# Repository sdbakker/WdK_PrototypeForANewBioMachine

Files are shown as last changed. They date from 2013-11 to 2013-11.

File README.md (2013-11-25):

# Prototype for a new BioMachine

This repository contains the simplified and stripped version of [Prototype for a new Bio Machine](http://ivanhenriques.com/2012/09/25/prototype-for-a-new-biomachine/ "Prototype for a new Bio Machine") by [Ivan Henriques](http://ivanhenriques.com "Ivan Henriques").

## Description of Files

* JuremaController
  Containes the arduino source code
* PlantController
  Contains the hardware schematics and material list

### JuremaController
* __JuremaController.ino__
  The controller source code
* twi.c 
  I2C library source code
* twi.h
  I2C library header file
* arduino-libraries-CapacitiveSensor.zip
  Arduino libarary for capacitive sensing 

### PlantController
* PlantController.sch
  CadSoft Eagle simplified schematic file of the PlantController main board
* PlantController.brd
  CadSoft Eagle board file of the PlantController main board
* __PlantControllerSimplified.png__
  Imange of simplified schematic of the main controller board
* __PlantController_brd.png__
  Image of main controller board

* PC_CapSense.sch
  CadSoft Eagle simplified schematic file of the sensor add-on board
* PC_CapSense.brd
  CadSoft Eagle board file of the sensor add-on board
* __PlantControllerSensorBoardSimplified.png__
  Image of simplified schematic of sensor add-on board
* __PC_CapSense_brd.png__
  Image of sensor add-on board layout

* __PlantController_BOM.pdf__
  Bill of materials with order numbers and URLs

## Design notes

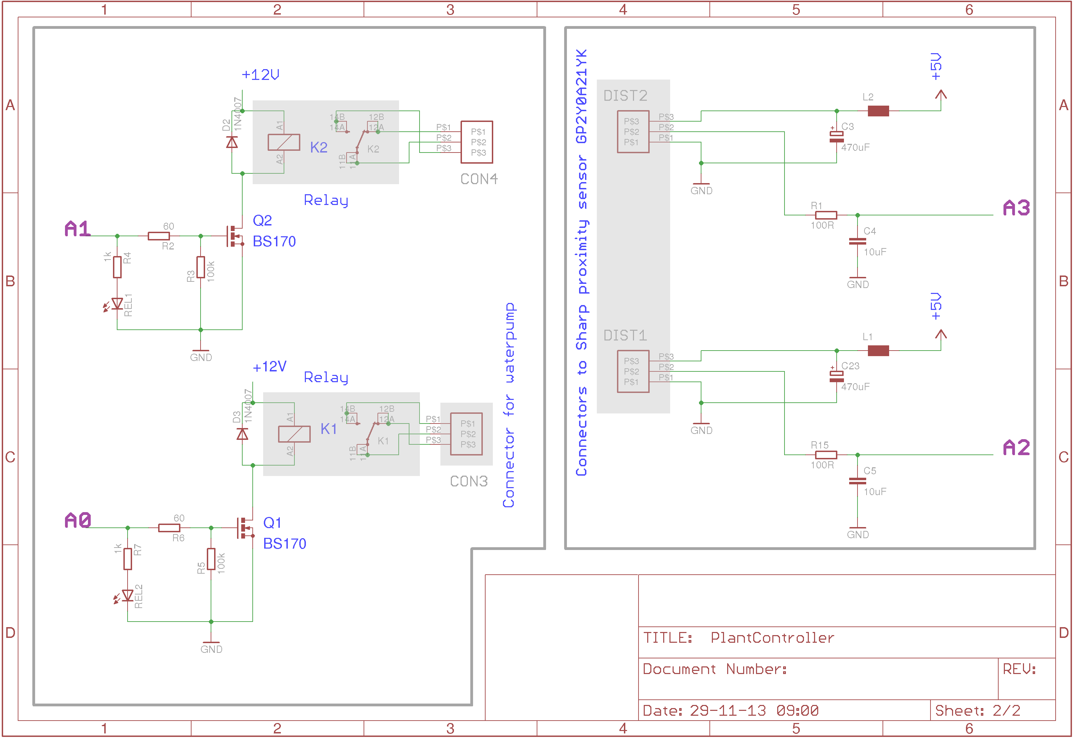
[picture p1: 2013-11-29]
PlantController/PlantControllerSimplified.png

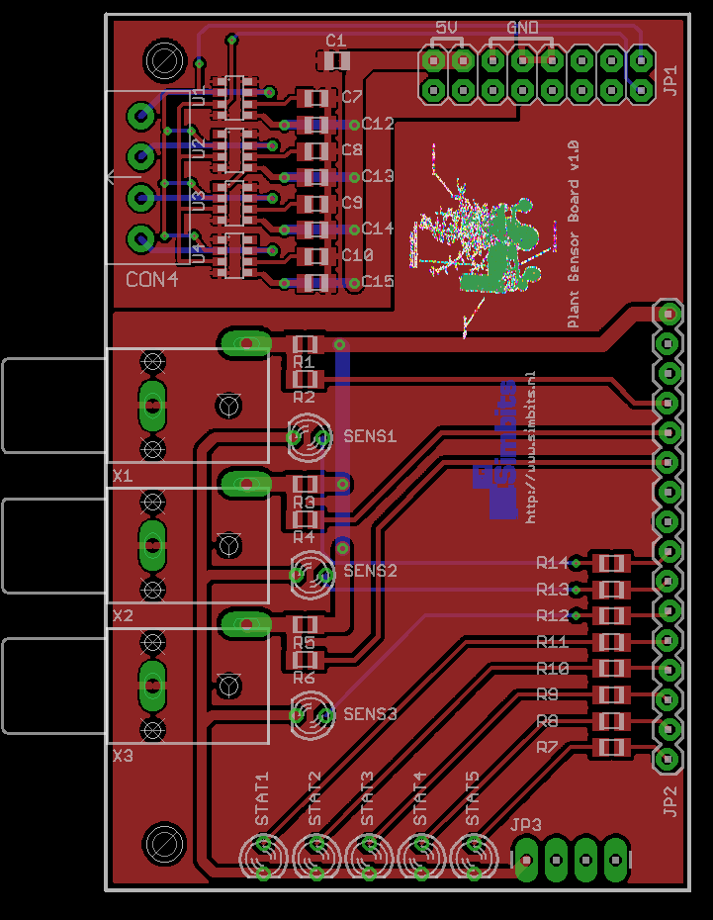
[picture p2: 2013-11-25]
PlantController/PC_CapSense_brd.png

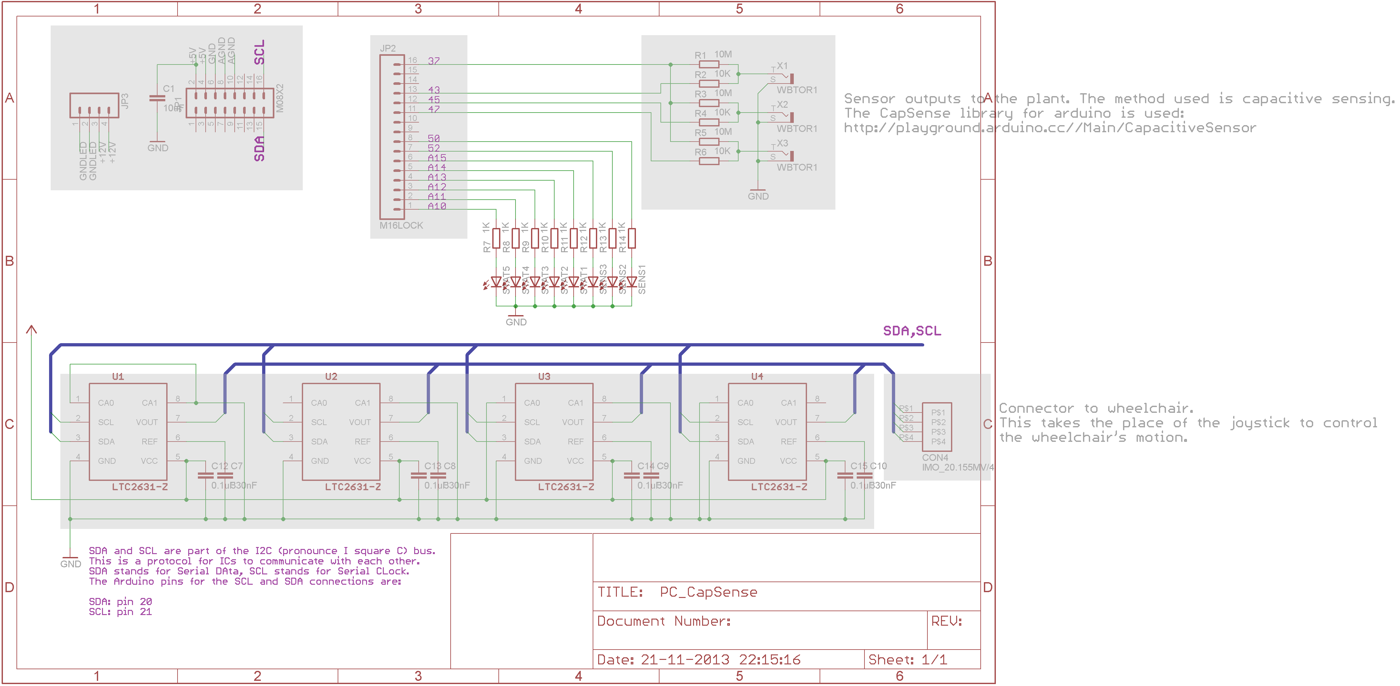
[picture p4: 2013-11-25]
PlantController/PlantControllerSensorBoardSimplified.png

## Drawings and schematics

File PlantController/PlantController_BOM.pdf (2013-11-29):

## PlantController_BOM

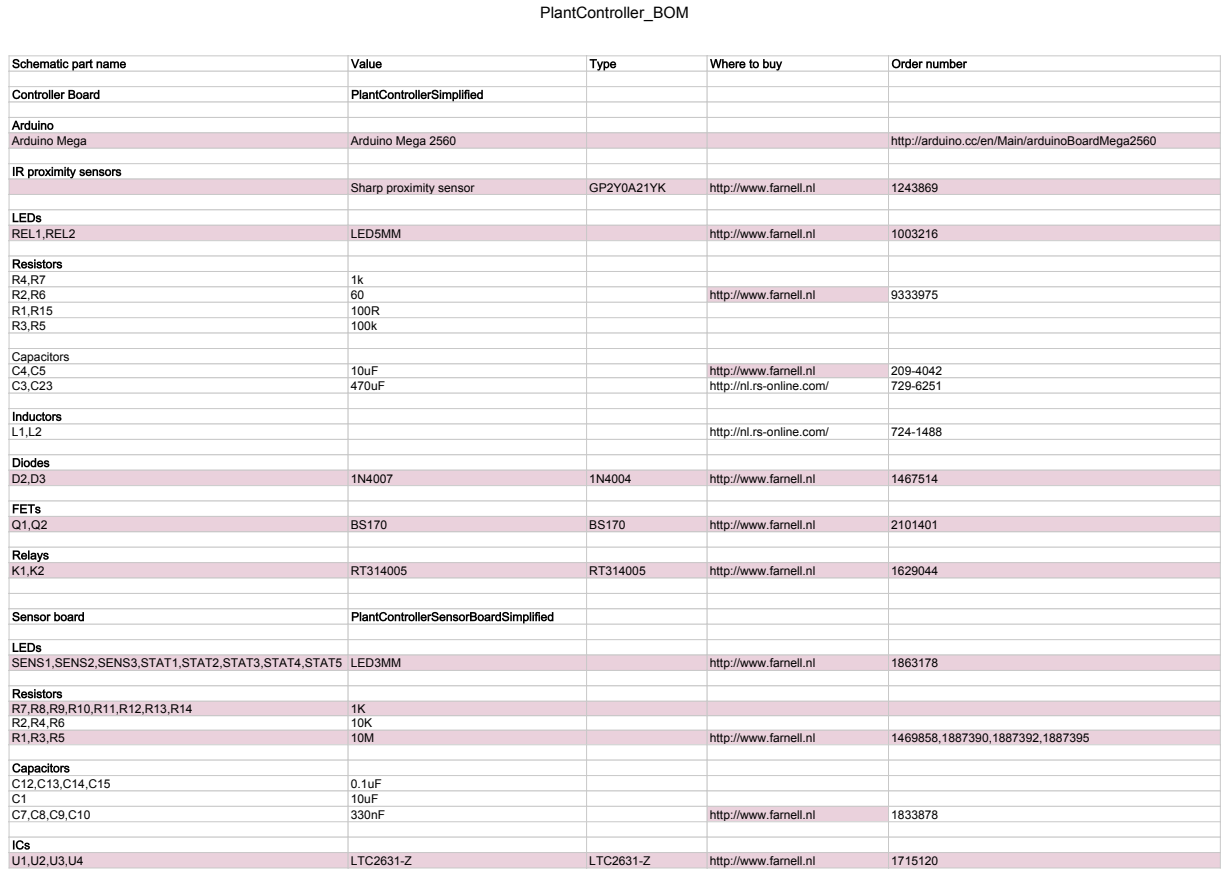
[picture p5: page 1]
Schematic part name; Value; Type; Where to buy; Order number; Controller Board; PlantControllerSimplified; Sensor board; PlantControllerSensorBoardSimplified

Arduino
Arduino Mega | Arduino Mega 2560 | http://arduino.cc/en/Main/arduinoBoardMega2560

IR proximity sensors

Sharp proximity sensor | GP2Y0A21YK | http://www.farnell.nl | 1243869

LEDs
REL1,REL2 | LED5MM | http://www.farnell.nl | 1003216

Resistors
R4,R7 | 1k
R2,R6 | 60 | http://www.farnell.nl | 9333975
R1,R15 | 100R
R3,R5 | 100k

Capacitors
C4,C5 | 10uF | http://www.farnell.nl | 209-4042
C3,C23 | 470uF | http://nl.rs-online.com/ | 729-6251

Inductors
L1,L2 | http://nl.rs-online.com/ | 724-1488

Diodes
D2,D3 | 1N4007 | 1N4004 | http://www.farnell.nl | 1467514

FETs
Q1,Q2 | BS170 | BS170 | http://www.farnell.nl | 2101401

Relays
K1,K2 | RT314005 | RT314005 | http://www.farnell.nl | 1629044

SENS1,SENS2,SENS3,STAT1,STAT2,STAT3,STAT4,STAT5 | LED3MM | http://www.farnell.nl | 1863178

R7,R8,R9,R10,R11,R12,R13,R14 | 1K
R2,R4,R6 | 10K
R1,R3,R5 | 10M | http://www.farnell.nl | 1469858,1887390,1887392,1887395

C12,C13,C14,C15 | 0.1uF
C1 | 10uF
C7,C8,C9,C10 | 330nF | http://www.farnell.nl | 1833878

ICs
U1,U2,U3,U4 | LTC2631-Z | LTC2631-Z | http://www.farnell.nl | 1715120

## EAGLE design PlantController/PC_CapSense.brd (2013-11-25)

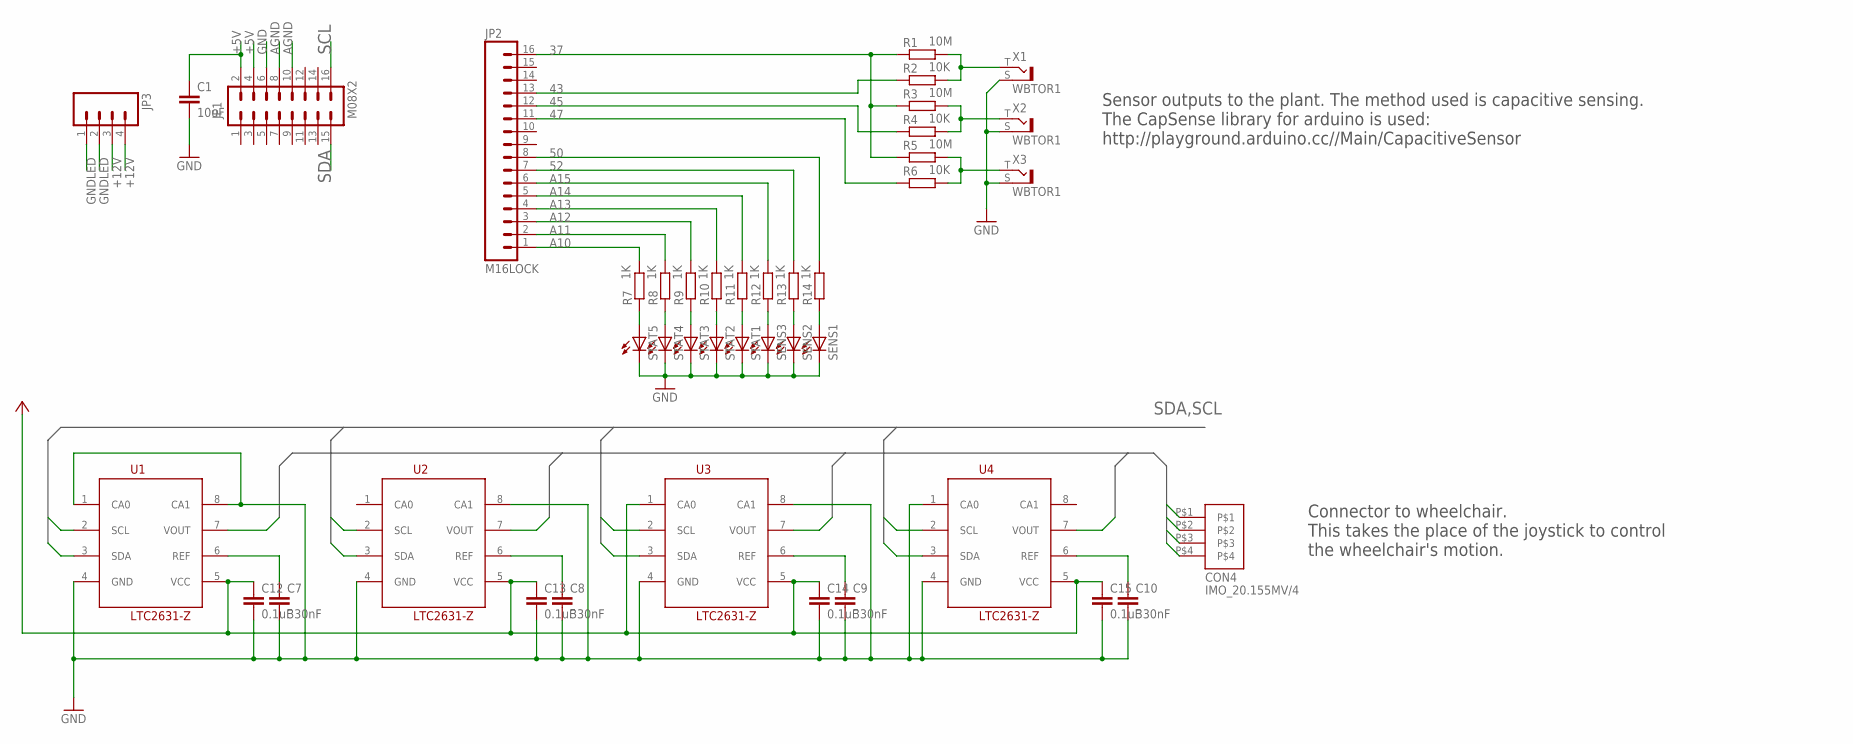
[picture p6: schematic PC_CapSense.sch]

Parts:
C1: 10uF; C0805
C7, C8, C9, C10: 330nF; C0805K
C12, C13, C14, C15: 0.1uF; C0805K
CON4: IMO_20.155MV/4
JP1: M08X2; 2X8
JP2: M16LOCK; 1X16_LOCK
JP3: M04LONGPADS; 1X04_LONGPADS
R1, R3, R5: 10M; M0805
R2, R4, R6: 10K; M0805
R7, R8, R9, R10, R11, R12, R13, R14: 1K; M0805
SENS1, SENS2, SENS3: LED3MM
STAT1, STAT2, STAT3, STAT4, STAT5: LED3MM
U1, U2, U3, U4: LTC2631-Z; TSOT23-8
X1, X2, X3: WBTOR1

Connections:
37: JP2.16, R1.1, R3.1, R5.1
43: JP2.13, R2.1
45: JP2.12, R4.1
47: JP2.11, R6.1
50: JP2.8, R14.2
52: JP2.7, R13.2
+5V: C1.1, C12.1, C13.1, C14.1, C15.1, JP1.2, JP1.4, U1.5 (VCC), U2.5 (VCC), U3.1 (CA0), U3.5 (VCC), U4.5 (VCC)
+12V: JP3.3, JP3.4
A10: JP2.1, R7.2
A11: JP2.2, R8.2
A12: JP2.3, R9.2
A13: JP2.4, R10.2
A14: JP2.5, R11.2
A15: JP2.6, R12.2
AGND: JP1.8, JP1.10, X1.S, X2.S, X3.S
GND: C1.2, C7.2, C8.2, C9.2, C10.2, C12.2, C13.2, C14.2, C15.2, JP1.6, U1.1 (CA0), U1.4 (GND), U1.8 (CA1), U2.4 (GND), U2.8 (CA1), U3.4 (GND), U3.8 (CA1), U4.1 (CA0), U4.4 (GND)
GNDLED: JP3.1, JP3.2, SENS1.K (C), SENS2.K (C), SENS3.K (C), STAT1.K (C), STAT2.K (C), STAT3.K (C), STAT4.K (C), STAT5.K (C)
unnamed: R1.2, R2.2, X1.T
unnamed: R3.2, R4.2, X2.T
unnamed: R5.2, R6.2, X3.T
unnamed: R7.1, STAT5.A
unnamed: R8.1, STAT4.A
unnamed: R9.1, STAT3.A
unnamed: R10.1, STAT2.A
unnamed: R11.1, STAT1.A
unnamed: R12.1, SENS3.A
unnamed: R13.1, SENS2.A
unnamed: R14.1, SENS1.A
unnamed: C10.1, U4.6 (REF)
unnamed: C9.1, U3.6 (REF)
unnamed: C8.1, U2.6 (REF)
unnamed: C7.1, U1.6 (REF)
SCL: JP1.16, U1.2 (SCL), U2.2 (SCL), U3.2 (SCL), U4.2 (SCL)
SDA: JP1.15, U1.3 (SDA), U2.3 (SDA), U3.3 (SDA), U4.3 (SDA)
VOUT0: CON4.P$1, U1.7 (VOUT)
VOUT1: CON4.P$2, U2.7 (VOUT)
VOUT2: CON4.P$3, U3.7 (VOUT)
VOUT3: CON4.P$4, U4.7 (VOUT)

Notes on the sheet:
Sensor outputs to the plant. The method used is capacitive sensing. The CapSense library for arduino is used: http://playground.arduino.cc//Main/CapacitiveSensor
Connector to wheelchair. This takes the place of the joystick to control the wheelchair's motion.

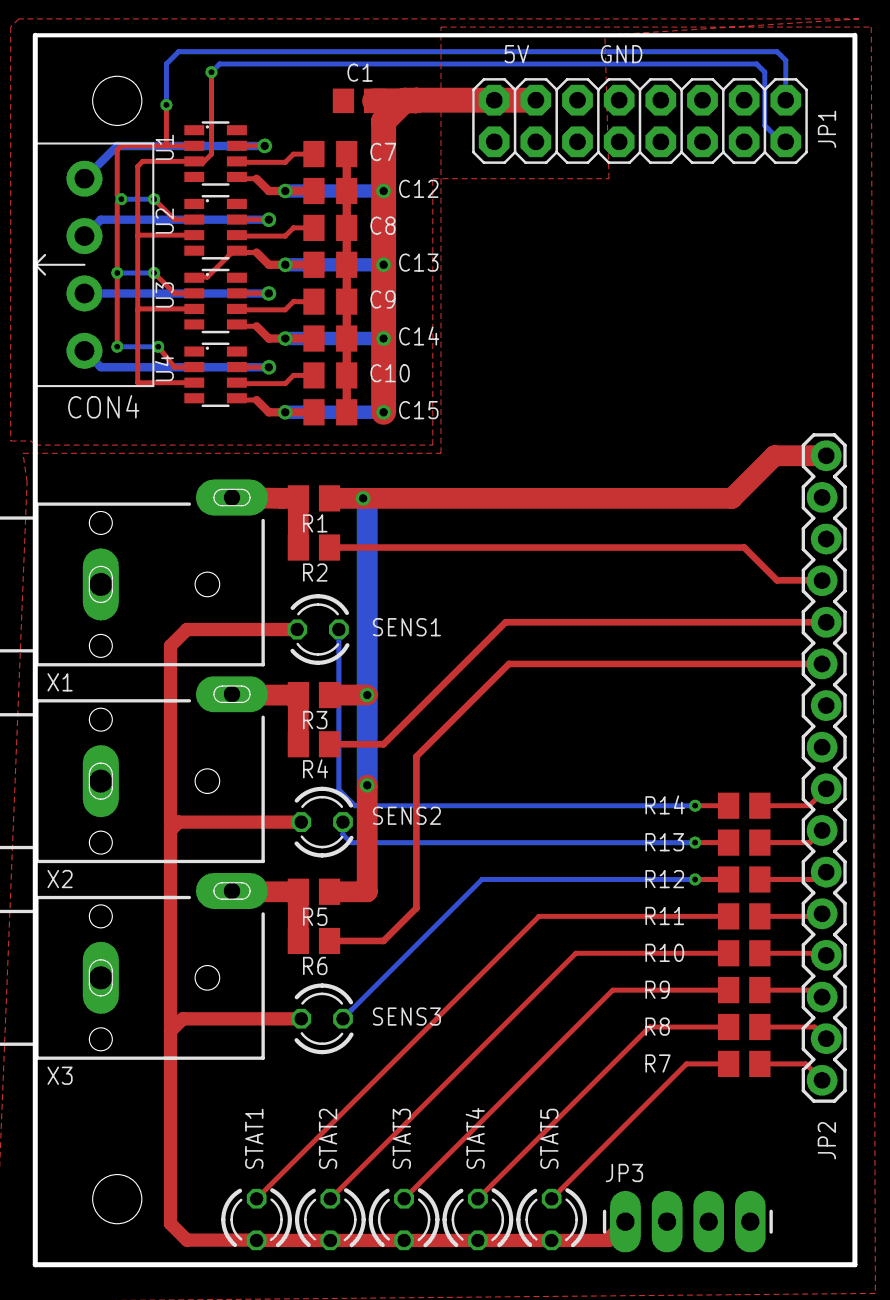
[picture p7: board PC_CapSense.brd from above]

Board: 2 copper layers, 50.0 x 75.0 mm, 42 parts (0 on the bottom side), 38 nets.

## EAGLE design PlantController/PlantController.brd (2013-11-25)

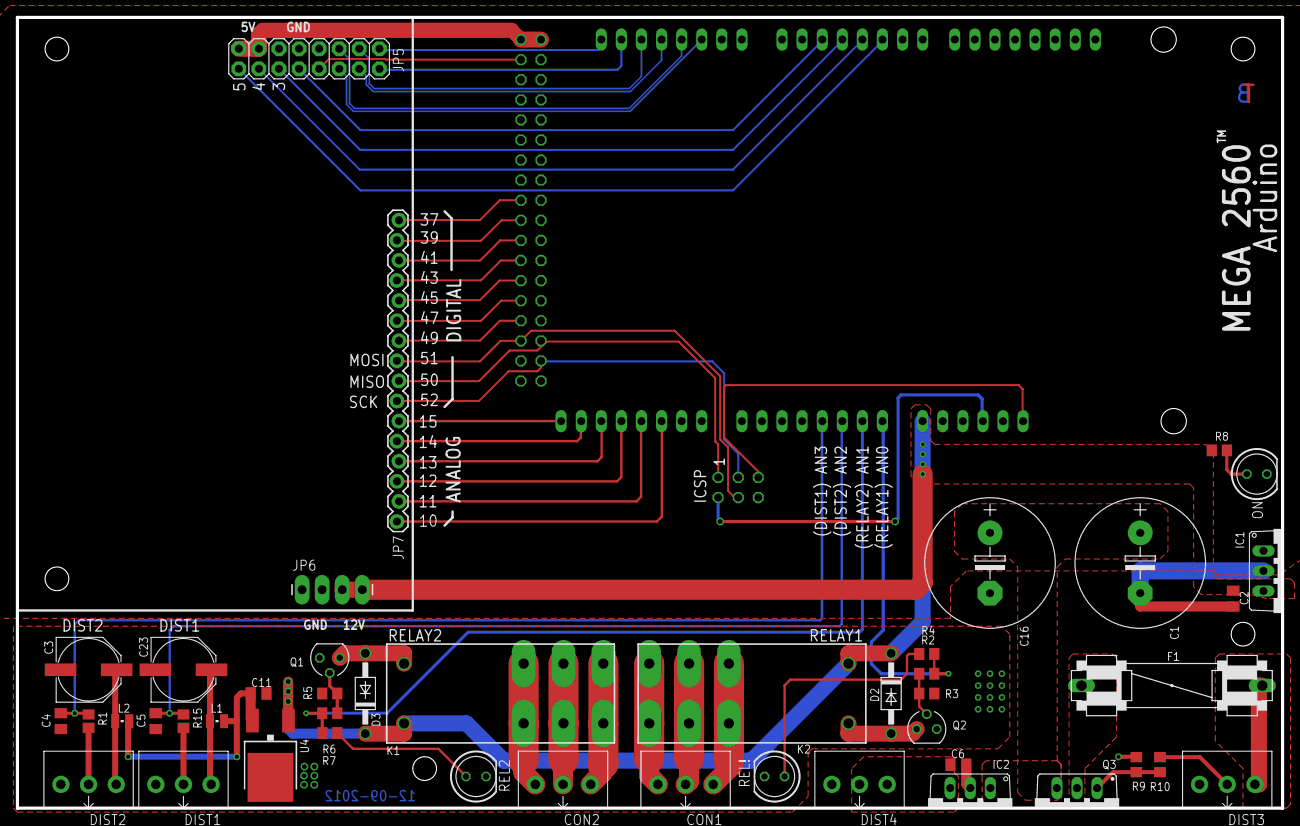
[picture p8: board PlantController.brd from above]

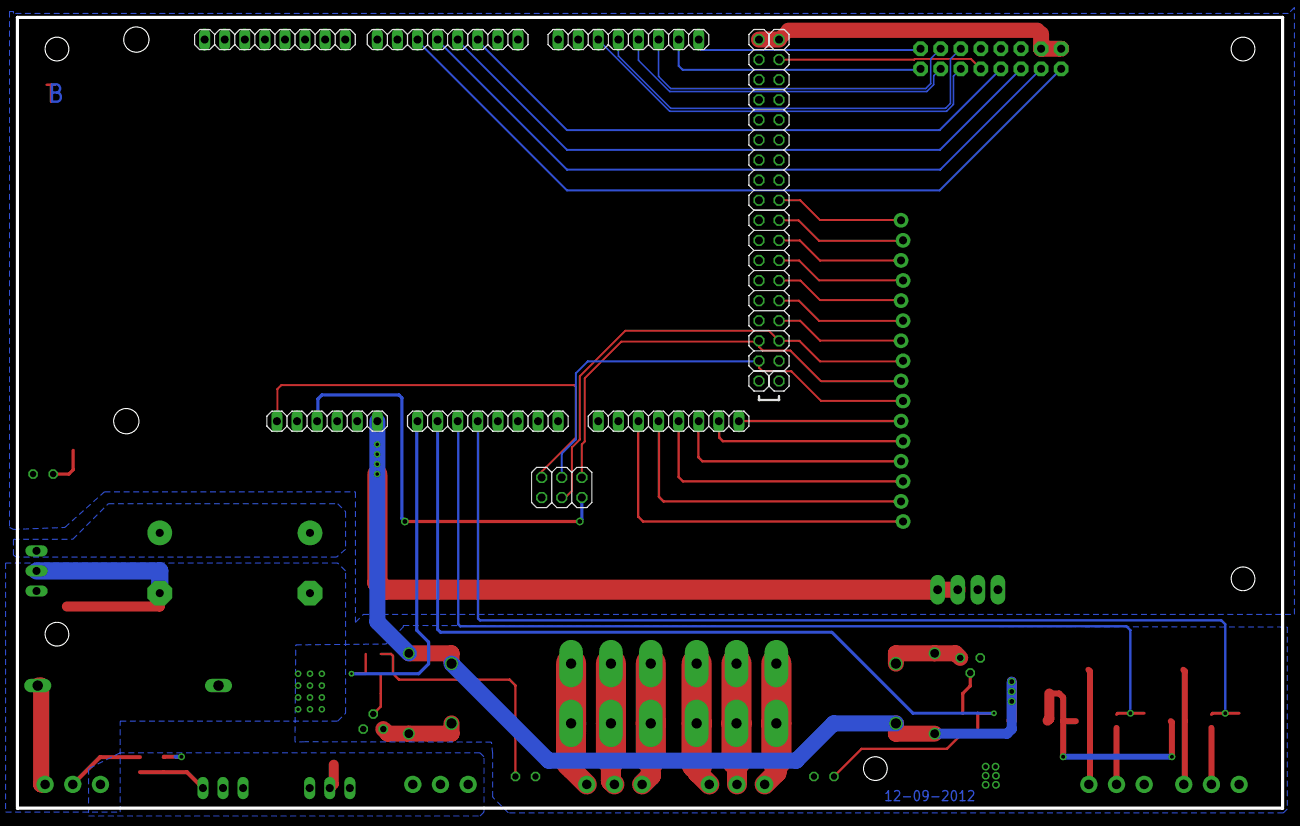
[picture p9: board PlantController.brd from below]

Board: 2 copper layers, 160.0 x 100.0 mm, 58 parts (13 on the bottom side), 59 nets.

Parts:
ADCH: 1X08
ADCL: 1X08
C1: 470uF; E7,5-16
C2, C6, C11: 100nF; C0805K
C3, C23: 470uF; PANASONIC_F
C4, C5: 10uF; C0805K
C16: 1000uF; E7,5-16
COMMUNICATION: 1X08
CON1, CON2: IMO_20.155MV/3
D2, D3: 1N4007; DO41-10
DIST1, DIST2, DIST3, DIST4: IMO_20.155MV/3
F1: FUSE
IC1, IC2: 7812TV; TO220V
ICSP: ICSP; 2X03
JP1, JP2, JP3, JP4: 1X01
JP5: M08X2; 2X8
JP6: 1X04_LONGPADS
JP7: M16LOCK; 1X16_LOCK
K1, K2: RT314005; RT-C/O16A5
L1, L2: WE-KI_0805_B
ON: LED5MM
POWER: 1X06
PWMH: 1X08
PWML: 1X08
Q1, Q2: BS170; SOT54E
Q3: IRF530; TO220BV
R1, R15: 100R; R0805
R2, R6, R10: 60; R0805
R3, R5, R9: 100k; R0805
R4, R7, R8: 1k; R0805
REL2: LED5MM
REL!: LED5MM
U4: MC7805BDTG; DPAK
XIOH: 2X08
XIOL: 2X08

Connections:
+5V: ICSP.2, JP1.1, JP2.1, JP5.2, JP5.4, POWER.3
+5V_SENS: C11.1, L1.1, L2.1, U4.3
+12V: C2.1, D2.C, D3.C, IC1.3, JP6.3, JP6.4, K1.A1, K2.A1, POWER.6, R8.1, U4.1
ADC0: ADCL.1, R2.2, R4.1
ADC1: ADCL.2, R6.2, R7.1
ADC2: ADCL.3, C5.1, R15.2
ADC3: ADCL.4, C4.1, R1.2
ADC10: ADCH.3, JP7.1
ADC11: ADCH.4, JP7.2
ADC12: ADCH.5, JP7.3
ADC13: ADCH.6, JP7.4
ADC14: ADCH.7, JP7.5
ADC15: ADCH.8, JP7.6
GND: C1.-, C2.2, C3.-, C4.2, C5.2, C6.2, C11.2, C16.-, C23.-, DIST1.P$1, DIST2.P$1, DIST3.P$1, DIST4.P$1, IC1.2, IC2.2, ICSP.6, JP3.1, JP4.1, JP5.6, JP5.8, JP5.10, JP6.1, JP6.2, ON.K, POWER.4, POWER.5, PWMH.7, Q1.S, Q2.S, R3.1, R5.1, R9.1, REL2.K, REL!.K, U4.4
unnamed: C6.1, DIST4.P$2, DIST4.P$3, IC2.3
unnamed: D2.A, K2.A2, Q2.D
unnamed: Q2.G, R2.1, R3.2
unnamed: D3.A, K1.A2, Q1.D
unnamed: R4.2, REL!.A
unnamed: Q1.G, R5.2, R6.1
unnamed: R7.2, REL2.A
unnamed: CON1.P$2, K2.11A, K2.11B
unnamed: CON1.P$3, K2.12A, K2.12B
unnamed: CON1.P$1, K2.14A, K2.14B
unnamed: CON2.P$2, K1.11A, K1.11B
unnamed: CON2.P$1, K1.12A, K1.12B
unnamed: CON2.P$3, K1.14A, K1.14B
unnamed: Q3.G, R9.2, R10.1
unnamed: DIST3.P$2, R10.2
unnamed: ON.A, R8.2
PA1: JP5.9, XIOH.15
PB1: ICSP.3, JP7.7, XIOL.2
PB2: ICSP.4, JP7.9, XIOL.3
PB3: ICSP.1, JP7.8, XIOL.4
PC0: JP7.16, XIOH.1
PE3: JP5.1, PWML.6
PE4: JP5.7, PWML.3
PE5: JP5.5, PWML.4
PG0: JP7.14, XIOL.13
PG2: JP7.15, XIOL.15
PG5: JP5.3, PWML.5
PL0: JP7.10, XIOL.5
PL2: JP7.11, XIOL.7
PL4: JP7.12, XIOL.9
PL6: JP7.13, XIOL.11
RESET: ICSP.5, POWER.1
RXD1: COMMUNICATION.3, JP5.14
RXD2: COMMUNICATION.5, JP5.12
SCL: COMMUNICATION.1, JP5.16
SDA: COMMUNICATION.2, JP5.15
SENSOR_POWER: C23.+, DIST1.P$3, L1.2
SENSOR_POWER1: C3.+, DIST2.P$3, L2.2
SHARP_SENSOR: DIST1.P$2, R15.1
SHARP_SENSOR1: DIST2.P$2, R1.1
TXD1: COMMUNICATION.4, JP5.13
TXD2: COMMUNICATION.6, JP5.11
VIN24: C1.+, C16.+, IC1.1, IC2.1, Q3.S
VINFIN: DIST3.P$3, F1.1
VINFOUT: F1.2, Q3.D

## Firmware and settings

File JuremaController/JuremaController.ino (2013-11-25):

#include <Arduino.h>
#include <CapSense.h>
#include <Wire.h>

#undef DBG
#undef DBG_CAPSENSE 
#undef TEST_MOTOR
#define ENABLE_PUMP

#define RELAY1_PIN					A0
#define RELAY2_PIN					A1
#define DIST1_PIN					A3
#define DIST2_PIN					A2	
#define DIST_FRONT_PIN				DIST2_PIN
#define DIST_BACK_PIN				DIST1_PIN

#define DIST_FRONT					0
#define DIST_BACK					1
#define DIST_FRONT_MASK				1
#define DIST_BACK_MASK				2
#define DIST_CAL_SAMPLES			30
#define DIST_DETECT_THRESHOLD		80

#define CAPSENSE_SENSORS			1
#define CAPSENSE_TOUCH_THRESHOLD	700
#define CAPSENSE_DRV_PIN			37
#define CAPSENSE_IN1_PIN			43
#define CAPSENSE_IN2_PIN			45
#define CAPSENSE_IN3_PIN			47
#define CAPSENSE_LED1_PIN			50
#define CAPSENSE_LED2_PIN			52
#define CAPSENSE_LED3_PIN			A15

#define LED_STAT1_PIN				A14
#define LED_STAT2_PIN				A13
#define LED_STAT3_PIN				A12
#define LED_STAT4_PIN				A11
#define LED_STAT5_PIN				A10

#define DAC_CMD_UPDATE				0x30
#define DAC_UD_ADDR					0x10
#define DAC_LR_ADDR 				0x11
#define DAC_REF_ADDR				0x12

#define DAC_UD_VHIGH				0xd0
#define DAC_UD_VMID					0xb0
#define DAC_UD_VLOW					0x90
#define DAC_LR_VHIGH				0xc5
#define DAC_LR_VMID					0xb0
#define DAC_LR_VLOW					0xa6
#define DAC_VREF					0xb0


typedef struct {
	uint8_t dac_vud;
	uint8_t dac_vlr;
	uint8_t dac_vref;
	uint16_t dist_cal_vals[2];
	uint8_t dist_an_pin[2];
	uint8_t dist_led_pin[2];
	CapSense *cs[CAPSENSE_SENSORS];
	uint8_t cs_led_pin[3];
	uint8_t funkyMove;
} juremaStc;

static juremaStc jurema;

static void updateDAC()
{
	Wire.beginTransmission(DAC_UD_ADDR); 
	Wire.write(DAC_CMD_UPDATE);       
	Wire.write(jurema.dac_vud);
	Wire.write((uint8_t)0x00);
	Wire.endTransmission();

	Wire.beginTransmission(DAC_LR_ADDR);
	Wire.write(DAC_CMD_UPDATE); 
	Wire.write(jurema.dac_vlr);
	Wire.write((uint8_t)0x00);
	Wire.endTransmission();

	Wire.beginTransmission(DAC_REF_ADDR);
	Wire.write(DAC_CMD_UPDATE);
	Wire.write(jurema.dac_vref);
	Wire.write((uint8_t)0x10);
	Wire.endTransmission();
}

static void resetDAC()
{
	jurema.dac_vud = DAC_UD_VMID;
	jurema.dac_vlr = DAC_LR_VMID;
	jurema.dac_vref = DAC_VREF;
	updateDAC();
}

static void calibrateDistanceSensors()
{
	int i, state, err = 0;
	uint16_t val_front = 0;
	uint16_t val_back = 0;

	jurema.dist_an_pin[DIST_FRONT] = DIST_FRONT_PIN;
	jurema.dist_an_pin[DIST_BACK] = DIST_BACK_PIN;
	jurema.dist_led_pin[DIST_FRONT] = LED_STAT1_PIN;
	jurema.dist_led_pin[DIST_BACK] = LED_STAT2_PIN;

	for (i=0; i<DIST_CAL_SAMPLES; i++) {
		val_front += analogRead(DIST_FRONT_PIN);
		val_back += analogRead(DIST_BACK_PIN);
	}

	val_front /= DIST_CAL_SAMPLES;
	val_back /= DIST_CAL_SAMPLES;

#if defined(DBG)	
	Serial.print("avg -> front: ");
	Serial.print(val_front);
	Serial.print(" - back: " );
	Serial.println(val_back);
#endif

	if (val_front > DIST_DETECT_THRESHOLD) {
		val_front = 0;
		err |= (DIST_FRONT_MASK);
	}

	if (val_back > DIST_DETECT_THRESHOLD) {
		val_back = 0;
		err |= (DIST_BACK_MASK);
	}

	jurema.dist_cal_vals[DIST_FRONT] = val_front;
	jurema.dist_cal_vals[DIST_BACK] = val_back;

	for (i=0,state=1; i<50; i++, state = !state) {
		if (err & DIST_FRONT_MASK) digitalWrite(LED_STAT1_PIN, state);
		if (err & DIST_BACK_MASK) digitalWrite(LED_STAT2_PIN, state);
		delay(50);
	}
}

static inline uint16_t distGetReading(int side)
{
	return analogRead(jurema.dist_an_pin[side]);
}

static inline uint8_t distDetectObject()
{
	uint8_t retmask = 0;
	long reading_front = distGetReading(DIST_FRONT);
	long reading_back = distGetReading(DIST_BACK);

#if defined(DBG)	
		Serial.print("front: ");
		Serial.print(reading_front);
		Serial.print(" - back: " );
		Serial.println(reading_back);
#endif

	if (reading_front > DIST_DETECT_THRESHOLD) {
		digitalWrite(jurema.dist_led_pin[DIST_FRONT], HIGH);
		retmask |= DIST_FRONT_MASK;
	} else {
		digitalWrite(jurema.dist_led_pin[DIST_FRONT], LOW);
	}

	if (reading_back > DIST_DETECT_THRESHOLD) {
		digitalWrite(jurema.dist_led_pin[DIST_BACK], HIGH);
		retmask |= DIST_BACK_MASK;
	} else {
		digitalWrite(jurema.dist_led_pin[DIST_BACK], LOW);
	}

	return retmask;
}

static int initCapSense()
{
	int i, state;

	for (i=0; i<CAPSENSE_SENSORS; i++) {
		jurema.cs[i] = new CapSense(CAPSENSE_DRV_PIN, CAPSENSE_IN1_PIN + i*2);
		jurema.cs[i]->set_CS_AutocaL_Millis(10000);
	}

	jurema.cs_led_pin[0] = CAPSENSE_LED1_PIN;
	jurema.cs_led_pin[1] = CAPSENSE_LED2_PIN;
	jurema.cs_led_pin[2] = CAPSENSE_LED3_PIN;
	
	for (i=0, state=1; i<4; i++,state=!state) {
		digitalWrite(CAPSENSE_LED1_PIN, state);
		digitalWrite(CAPSENSE_LED2_PIN, state);
		digitalWrite(CAPSENSE_LED3_PIN, state);
		delay(100);
	}

}

static inline long getCapSenseReading(int n, int samples)
{
	return jurema.cs[n]->capSense(samples);
}

static inline long isTouched(int n)
{
	long reading = getCapSenseReading(n, 30); 
#if defined(DBG_CAPSENSE)
	Serial.print(n);
	Serial.print(": ");
	Serial.println(reading);
#endif
	return (reading > CAPSENSE_TOUCH_THRESHOLD) ? reading : 0;
}

#if defined(ENABLE_PUMP)
static void waterPlant(int duration)
{
	digitalWrite(RELAY1_PIN, HIGH);
	delay(duration);
	digitalWrite(RELAY1_PIN, LOW);
}
#endif

static void funkyInitScene()
{
	int i;
	int state = 0;

	for (i=0; i<9; i++,state=!state) {
		digitalWrite(CAPSENSE_LED1_PIN, state);
		digitalWrite(CAPSENSE_LED2_PIN, state);
		digitalWrite(CAPSENSE_LED3_PIN, state);
		digitalWrite(LED_STAT1_PIN, state);
		digitalWrite(LED_STAT2_PIN, state);
		digitalWrite(LED_STAT3_PIN, state);
		digitalWrite(LED_STAT4_PIN, state);
		digitalWrite(LED_STAT5_PIN, state);
		delay(50);
	}

	digitalWrite(CAPSENSE_LED1_PIN, HIGH);
	delay(100);
	digitalWrite(CAPSENSE_LED2_PIN, HIGH);
	delay(100);
	digitalWrite(CAPSENSE_LED1_PIN, LOW);
	delay(100);
	digitalWrite(CAPSENSE_LED3_PIN, HIGH);
	delay(100);
	digitalWrite(CAPSENSE_LED2_PIN, LOW);
	delay(100);
	digitalWrite(LED_STAT1_PIN, HIGH);
	delay(100);
	digitalWrite(CAPSENSE_LED3_PIN, LOW);
	delay(100);
	digitalWrite(LED_STAT2_PIN, HIGH);
	delay(100);
	digitalWrite(LED_STAT1_PIN, LOW);
	delay(100);
	digitalWrite(LED_STAT3_PIN, HIGH);
	delay(100);
	digitalWrite(LED_STAT2_PIN, LOW);
	delay(100);
	digitalWrite(LED_STAT4_PIN, HIGH);
	delay(100);
	digitalWrite(LED_STAT3_PIN, LOW);
	delay(100);
	digitalWrite(LED_STAT5_PIN, HIGH);
	delay(100);
	digitalWrite(LED_STAT4_PIN, LOW);
	delay(100);
	digitalWrite(LED_STAT5_PIN, LOW);
}

void setup()
{
	Serial.begin(9600);

	Serial.println("Welcome to Jurema ActionPlant Development Edition");

	Wire.begin(); 
 	delay(100);

	Serial.println("Setting up DAC voltages");
	resetDAC();
  
	Serial.println("Seeding the random");
  	randomSeed(analogRead(A5));

	Serial.println("Initializing GPIO");
	pinMode(RELAY1_PIN, OUTPUT);
	pinMode(RELAY2_PIN, OUTPUT);
	pinMode(CAPSENSE_LED1_PIN, OUTPUT);
	pinMode(CAPSENSE_LED2_PIN, OUTPUT);
	pinMode(CAPSENSE_LED3_PIN, OUTPUT);
	pinMode(LED_STAT1_PIN, OUTPUT);
	pinMode(LED_STAT2_PIN, OUTPUT);
	pinMode(LED_STAT3_PIN, OUTPUT);
	pinMode(LED_STAT4_PIN, OUTPUT);
	pinMode(LED_STAT5_PIN, OUTPUT);

	Serial.println("Do some useless fancy blinking");
	funkyInitScene();

#if defined(ENABLE_PUMP)
	Serial.println("Water the plants");
	waterPlant(2000);
#endif

	Serial.println("Calibrate distance sensors");
	calibrateDistanceSensors();

	Serial.println("Initialize plant sensors");
	initCapSense();

	jurema.funkyMove = 0;

	Serial.println("");
	Serial.println("Ready for action");
}

#define MOVE_NONE		0
#define MOVE_FORWARD	1
#define MOVE_BACK		2
#define MOVE_LEFT		4
#define MOVE_RIGHT		8

static void _moveForward(int duration)
{
	uint8_t state = 1;

	if (distDetectObject() & DIST_FRONT_MASK) 
		return;

	jurema.dac_vud = DAC_UD_VHIGH;
	updateDAC();

	do {
		uint8_t detect_mask;
		delay(10);
		digitalWrite(LED_STAT4_PIN, state);

		detect_mask= distDetectObject();
		if (detect_mask & DIST_FRONT_MASK) {
			Serial.println("Object detected in the front! aborting move");
			break;
		}

		state = !state;
	} while (--duration);

	digitalWrite(LED_STAT4_PIN, LOW);
	resetDAC();
}

static void _moveBackward(int duration)
{
	uint8_t state = 1;

	if (distDetectObject() & DIST_BACK_MASK) 
		return;

	jurema.dac_vud = DAC_UD_VLOW;
	updateDAC();

	do {
		delay(10);
		digitalWrite(LED_STAT4_PIN, state);

		if (distDetectObject() & DIST_BACK_MASK) {
			Serial.println("Object detected in the back! aborting move");
			break;
		}

		state = !state;
	} while (--duration);

	digitalWrite(LED_STAT4_PIN, LOW);
	resetDAC();
}

static void _moveLeft(int duration)
{
	uint8_t state = 1;

	jurema.dac_vlr = DAC_LR_VLOW;
	updateDAC();

	do {
		delay(10);
		digitalWrite(LED_STAT5_PIN, state);
		state = !state;
/*
		if (distDetectObject()) {
			Serial.println("Object detected! aborting move");
			break;
		}
*/
	} while (--duration);

	digitalWrite(LED_STAT5_PIN, LOW);
	resetDAC();
}

static void _moveRight(int duration)
{
	uint8_t state = 1;
	jurema.dac_vlr = DAC_LR_VHIGH;
	updateDAC();

	do {
		delay(10);
		digitalWrite(LED_STAT5_PIN, state);
		state = !state;
/*
		if (distDetectObject()) {
			Serial.println("Object detected! aborting move");
			break;
		}
*/
	} while (--duration);

	digitalWrite(LED_STAT5_PIN, LOW);
	resetDAC();
}

static void doMove(uint8_t move, int duration)
{
	switch (move)
	{
		case MOVE_FORWARD:
			Serial.println("Move forward");
			_moveForward(duration);
			break;
		case MOVE_BACK:
			Serial.println("Move backward");
			_moveBackward(duration);
			break;
		case MOVE_LEFT:
			Serial.println("Move left");
			_moveLeft(duration);
			break;
		case MOVE_RIGHT:
			Serial.println("Move right");
			_moveRight(duration);
			break;
		default:
			break;
	}
}

static void funkyMove(uint8_t move)
{
	Serial.print("FunkyMove nr: ");
	Serial.println(move);

	switch (move) {
		case 0:
			doMove(MOVE_BACK, 175);
			doMove(MOVE_LEFT, 150);
			doMove(MOVE_BACK, 100);
			break;

		case 1:
			doMove(MOVE_RIGHT, 150);
			doMove(MOVE_BACK, 100);
			delay(1000);
			doMove(MOVE_RIGHT, 150);
			doMove(MOVE_FORWARD, 175);
			break;

		case 2:	
			doMove(MOVE_RIGHT, 100);
			delay(1000);
			doMove(MOVE_RIGHT, 150);
			doMove(MOVE_FORWARD, 175);
			doMove(MOVE_LEFT, 150);
			doMove(MOVE_BACK, 175);
			break;

		case 3:	
			doMove(MOVE_BACK, 175);
			doMove(MOVE_LEFT, 100);
			doMove(MOVE_BACK, 175);
			doMove(MOVE_LEFT, 100);
			doMove(MOVE_BACK, 100);
			doMove(MOVE_FORWARD, 175);
			break;
		
		case 4:
			doMove(MOVE_LEFT, 100);
			doMove(MOVE_BACK, 175);
			delay(1000);
			doMove(MOVE_RIGHT, 150);
			doMove(MOVE_BACK, 150);
			doMove(MOVE_LEFT, 150);
			doMove(MOVE_BACK, 100);
			break;
			
		case 5:
			doMove(MOVE_LEFT, 100);
			doMove(MOVE_BACK, 175);
			delay(1000);
			doMove(MOVE_RIGHT, 100);
			doMove(MOVE_BACK, 100);
			break;

		case 6:
			doMove(MOVE_RIGHT, 100);
			doMove(MOVE_BACK, 175);
			delay(1000);
			doMove(MOVE_RIGHT, 100);
			doMove(MOVE_BACK, 100);
			doMove(MOVE_FORWARD, 175);
			doMove(MOVE_RIGHT, 100);
			doMove(MOVE_BACK, 100);
			break;
	
		case 7:	
			doMove(MOVE_RIGHT, 100);
			doMove(MOVE_BACK, 100);
			doMove(MOVE_FORWARD, 175);
			doMove(MOVE_RIGHT, 100);
			doMove(MOVE_BACK, 100);
			break;

		default:
			break;
	}
}

static uint8_t selectMove()
{
	uint8_t detect_mask = distDetectObject();

	Serial.println("Selecting move");
	if ((detect_mask & DIST_FRONT_MASK) & (detect_mask & DIST_BACK_MASK)) {
		Serial.println("Objects detected on both sides");
		Serial.print("Action: ");
		doMove(MOVE_RIGHT, 175);
	} else if (detect_mask & DIST_FRONT_MASK) {
		Serial.println("Objects detected in front");
		Serial.print("Action: ");
		doMove(MOVE_BACK, 175);
		doMove(MOVE_RIGHT, 100);
	} else if (detect_mask & DIST_BACK_MASK) {
		Serial.println("Objects detected in the back");
		Serial.print("Action: ");
		doMove(MOVE_FORWARD, 175);
		doMove(MOVE_LEFT, 100);
		doMove(MOVE_FORWARD, 175);
	} else {
		//long r = random(7);
		Serial.println("No objects detected, free to move");
		Serial.print("Action: ");
		funkyMove(jurema.funkyMove++);
		if (jurema.funkyMove > 7)
			jurema.funkyMove = 0;
	}

	Serial.println("Move finished");
	resetDAC();
	delay(1000);
}

#if defined(TEST_MOTOR)
void testMotor()
{
	Serial.println("Test forward");
	doMove(MOVE_FORWARD, 20);
	delay(2000);
	Serial.println("Test backward");
	doMove(MOVE_BACK, 20);
	delay(2000);
	Serial.println("Test left");
	doMove(MOVE_LEFT, 20);
	delay(2000);
	Serial.println("Test right");
	doMove(MOVE_RIGHT, 20);
	delay(2000);
}
#endif

void loop()
{
	int i;

#if defined(TEST_MOTOR)
	testMotor();
#endif

	for (i=0; i<CAPSENSE_SENSORS; i++) {
		if (isTouched(i)) {
			Serial.println("Have touch");
			digitalWrite(jurema.cs_led_pin[i], HIGH);		
			selectMove();
			delay(2000);
			Serial.println("Recalibrate touch");
			jurema.cs[i]->reset_CS_AutoCal();
			Serial.println("Done");
			Serial.println("");
			break;
		} else {
			digitalWrite(jurema.cs_led_pin[i], LOW);		
		}
	}

	distDetectObject();
}

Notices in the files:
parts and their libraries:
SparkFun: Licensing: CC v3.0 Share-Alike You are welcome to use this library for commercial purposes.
